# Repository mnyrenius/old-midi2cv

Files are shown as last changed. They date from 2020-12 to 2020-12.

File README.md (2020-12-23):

# old-midi2cv

PCB design + software for a midi2cv eurorack module.

I created it in 2016 and it has been installed in my rack since then.
It doesn't have any cool features and is probably really crappy, but it kind of works.

## Schematics




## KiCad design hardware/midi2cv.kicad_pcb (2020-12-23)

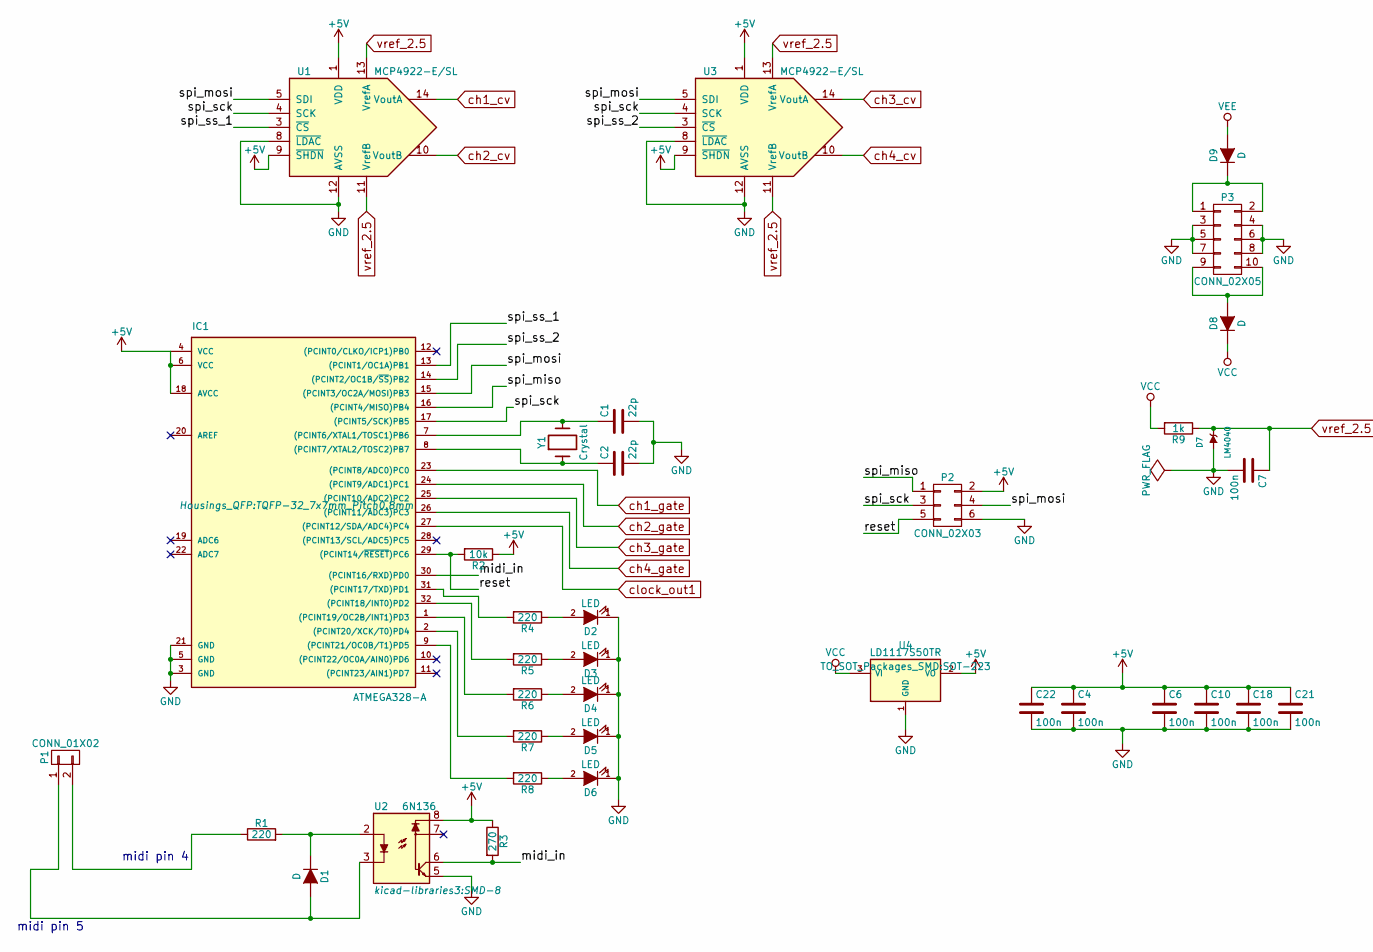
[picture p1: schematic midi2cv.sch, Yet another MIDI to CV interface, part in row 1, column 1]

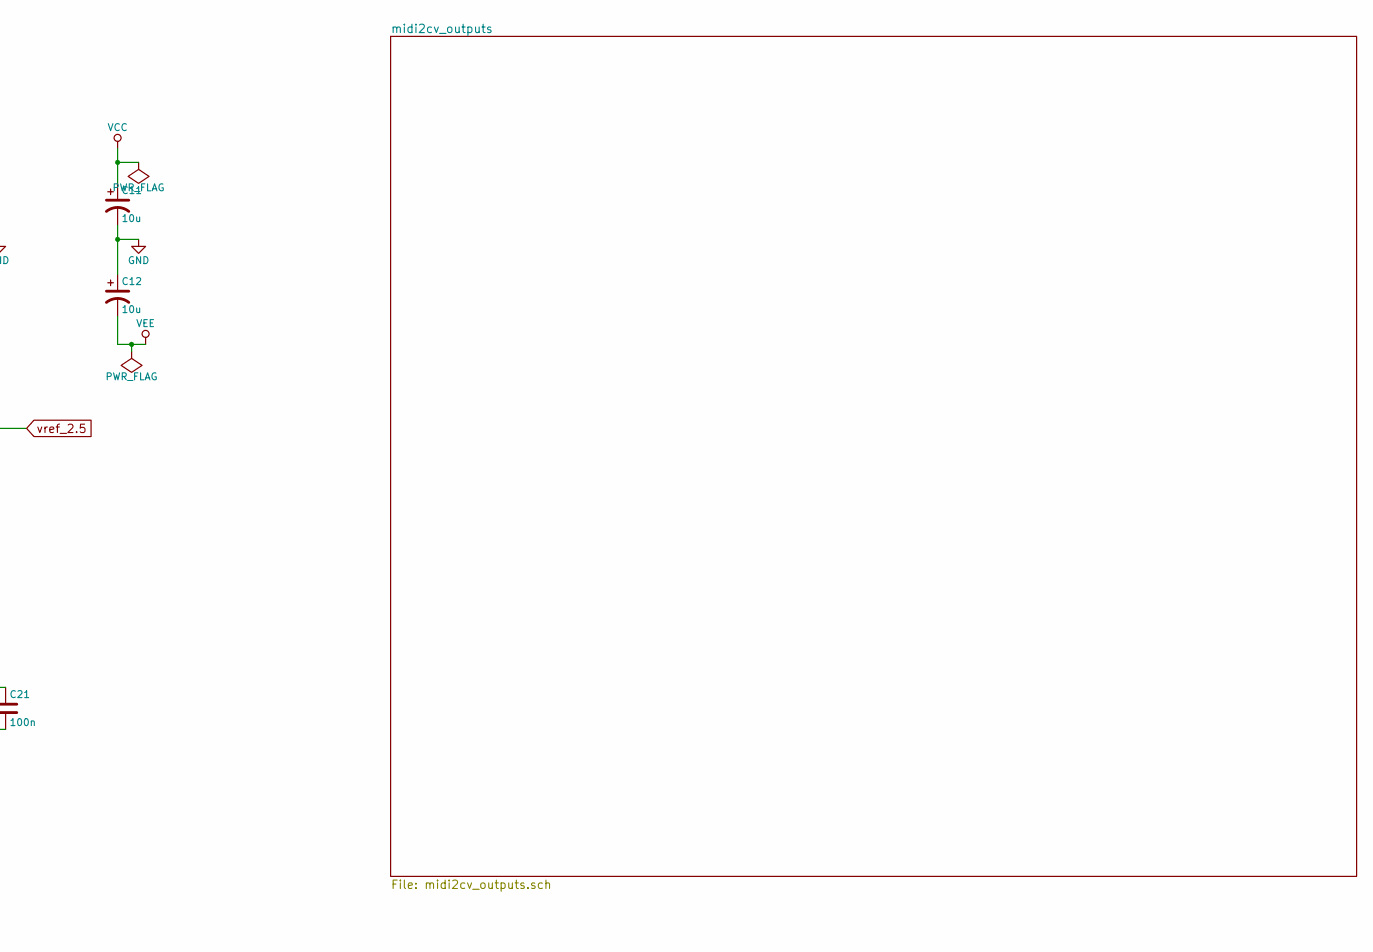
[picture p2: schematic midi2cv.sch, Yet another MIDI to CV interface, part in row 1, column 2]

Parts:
C1, C2: 22p; C_0603_HandSoldering
C4, C6, C7, C10, C18, C21, C22: 100n; C_0603_HandSoldering
C11, C12: 10u; c_elec_4x5.3
D1, D8, D9: D; SOD123
D2, D3, D4, D5, D6: LED; LED-3MM
D7: LM4040; SOT-23
IC1: ATMEGA328-A; TQFP-32_7x7mm_Pitch0.8mm
P1: CONN_01X02; Pin_Header_Straight_1x02
P2: CONN_02X03; Pin_Header_Straight_2x03
P3: CONN_02X05; Pin_Header_Straight_2x05
R1, R4, R5, R6, R7, R8: 220; R_0603_HandSoldering
R2: 10k; R_0603_HandSoldering
R3: 270; R_0603_HandSoldering
R9: 1k; R_0603_HandSoldering
U1, U3: MCP4922-E/SL; SOIC-14_N
U2: 6N136; SMD-8
U4: LD1117S50TR; SOT-223
Y1: Crystal; Crystal_HC49-SD_SMD

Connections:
+5V: C4.1, C6.1, C10.1, C18.1, C21.1, C22.1, IC1.4 (VCC), IC1.6 (VCC), IC1.18 (AVCC), P2.2, R2.1, R3.1, U1.1 (VDD), U1.9 (~SHDN~), U2.8, U3.1 (VDD), U3.9 (~SHDN~), U4.2 (VO)
/midi_in: IC1.30 ((PCINT16/RXD)PD0), R3.2, U2.6
/reset: IC1.29 ((PCINT14/~RESET~)PC6), P2.5, R2.2
/spi_miso: IC1.16 ((PCINT4/MISO)PB4), P2.1
/spi_mosi: IC1.15 ((PCINT3/OC2A/MOSI)PB3), P2.4, U1.5 (SDI), U3.5 (SDI)
/spi_sck: IC1.17 ((PCINT5/SCK)PB5), P2.3, U1.4 (SCK), U3.4 (SCK)
/spi_ss_1: IC1.13 ((PCINT1/OC1A)PB1), U1.3 (~CS~)
/spi_ss_2: IC1.14 ((PCINT2/OC1B/~SS~)PB2), U3.3 (~CS~)
GND: C1.2, C2.2, C4.2, C6.2, C7.2, C10.2, C11.2, C12.1, C18.2, C21.2, C22.2, D2.1 (K), D3.1 (K), D4.1 (K), D5.1 (K), D6.1 (K), D7.2 (A), IC1.3 (GND), IC1.5 (GND), IC1.21 (GND), P2.6, P3.3, P3.4, P3.5, P3.6, P3.7, P3.8, U1.8 (~LDAC~), U1.12 (AVSS), U2.5, U3.8 (~LDAC~), U3.12 (AVSS), U4.1 (GND); also elsewhere on the board
unnamed: C1.1, IC1.7 ((PCINT6/XTAL1/TOSC1)PB6), Y1.2
unnamed: C2.1, IC1.8 ((PCINT7/XTAL2/TOSC2)PB7), Y1.1
unnamed: D1.1 (K), R1.2, U2.2
unnamed: D1.2 (A), P1.1, U2.3
unnamed: D2.2 (A), R4.1
unnamed: D3.2 (A), R5.1
unnamed: D4.2 (A), R6.1
unnamed: D5.2 (A), R7.1
unnamed: D6.2 (A), R8.1
unnamed: D8.2 (A), P3.9, P3.10
unnamed: D9.1 (K), P3.1, P3.2
unnamed: IC1.1 ((PCINT19/OC2B/INT1)PD3), R6.2
unnamed: IC1.2 ((PCINT20/XCK/T0)PD4), R7.2
unnamed: IC1.9 ((PCINT21/OC0B/T1)PD5), R8.2
unnamed: IC1.31 ((PCINT17/TXD)PD1), R4.2
unnamed: IC1.32 ((PCINT18/INT0)PD2), R5.2
unnamed: P1.2, R1.1
VCC: C11.1, D8.1 (K), R9.2, U4.3 (VI); also elsewhere on the board
VEE: C12.2, D9.2 (A); also elsewhere on the board
ch1_cv: U1.14 (VoutA); also elsewhere on the board
ch1_gate: IC1.23 ((PCINT8/ADC0)PC0); also elsewhere on the board
ch2_cv: U1.10 (VoutB); also elsewhere on the board
ch2_gate: IC1.24 ((PCINT9/ADC1)PC1); also elsewhere on the board
ch3_cv: U3.14 (VoutA); also elsewhere on the board
ch3_gate: IC1.25 ((PCINT10/ADC2)PC2); also elsewhere on the board
ch4_cv: U3.10 (VoutB); also elsewhere on the board
ch4_gate: IC1.26 ((PCINT11/ADC3)PC3); also elsewhere on the board
clock_out1: IC1.27 ((PCINT12/SDA/ADC4)PC4); also elsewhere on the board
vref_2.5: C7.1, D7.1 (K), R9.1, U1.11 (VrefB), U1.13 (VrefA), U3.11 (VrefB), U3.13 (VrefA); also elsewhere on the board

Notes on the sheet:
midi pin 4
midi pin 5

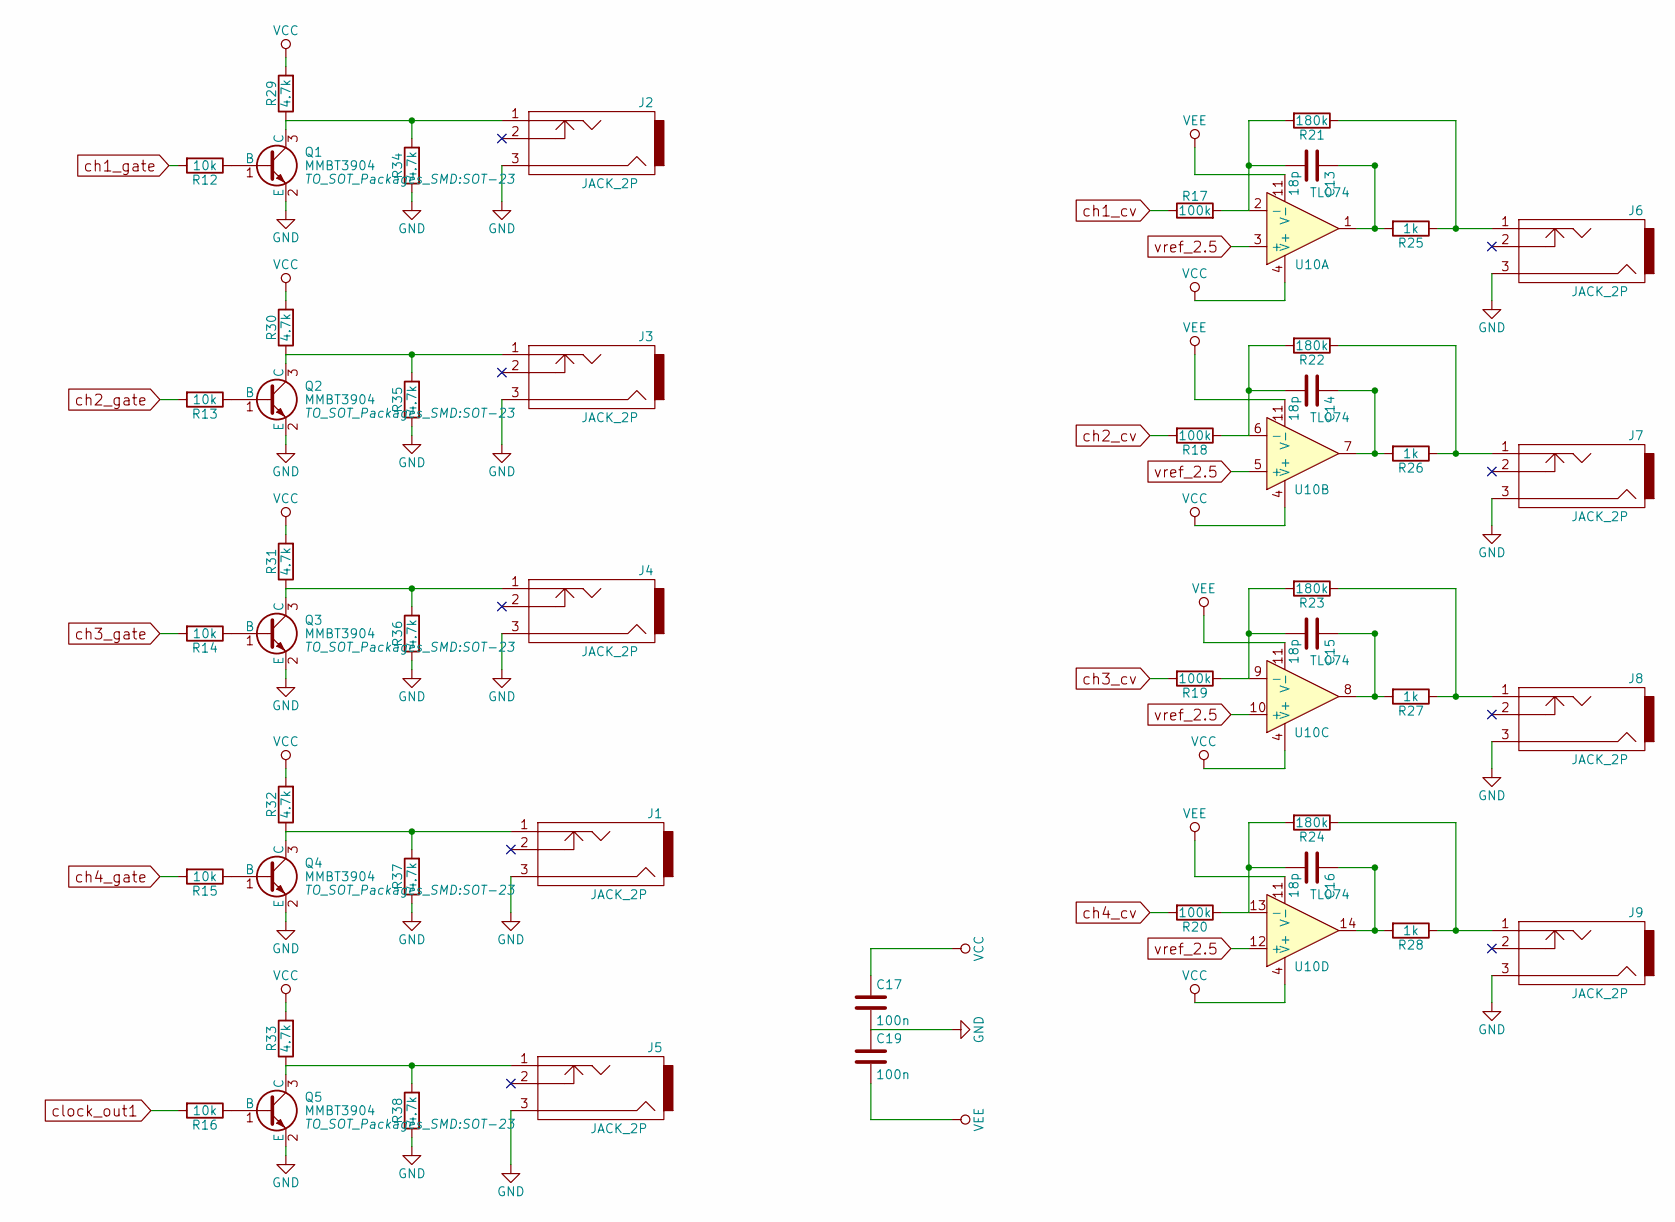
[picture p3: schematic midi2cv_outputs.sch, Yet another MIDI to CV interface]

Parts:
C13, C14, C15, C16: 18p; C_0603_HandSoldering
C17, C19: 100n; C_0603_HandSoldering
J1, J2, J3, J4, J5, J6, J7, J8, J9: JACK_2P; THONKICONN2
Q1, Q2, Q3, Q4, Q5: MMBT3904; SOT-23
R12, R13, R14, R15, R16: 10k; R_0603_HandSoldering
R17, R18, R19, R20: 100k; R_0603_HandSoldering
R21, R22, R23, R24: 180k; R_0603_HandSoldering
R25, R26, R27, R28: 1k; R_0603_HandSoldering
R29, R30, R31, R32, R33, R34, R35, R36, R37, R38: 4.7k; R_0603_HandSoldering
U10: TL074; SOIC-14_N

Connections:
GND: C17.2, C19.1, J1.3, J2.3, J3.3, J4.3, J5.3, J6.3, J7.3, J8.3, J9.3, Q1.2 (E), Q2.2 (E), Q3.2 (E), Q4.2 (E), Q5.2 (E), R34.1, R35.1, R36.1, R37.1, R38.1; also elsewhere on the board
unnamed: C13.1, R25.2, U10.1
unnamed: C13.2, R17.2, R21.2, U10.2 (-)
unnamed: C14.1, R26.2, U10.7
unnamed: C14.2, R18.1, R22.2, U10.6 (-)
unnamed: C15.1, R27.2, U10.8
unnamed: C15.2, R19.1, R23.2, U10.9 (-)
unnamed: C16.1, R28.2, U10.14
unnamed: C16.2, R20.1, R24.2, U10.13 (-)
unnamed: J1.1, Q4.3 (C), R32.1, R37.2
unnamed: J2.1, Q1.3 (C), R29.1, R34.2
unnamed: J3.1, Q2.3 (C), R30.1, R35.2
unnamed: J4.1, Q3.3 (C), R31.1, R36.2
unnamed: J5.1, Q5.3 (C), R33.1, R38.2
unnamed: J6.1, R21.1, R25.1
unnamed: J7.1, R22.1, R26.1
unnamed: J8.1, R23.1, R27.1
unnamed: J9.1, R24.1, R28.1
unnamed: Q1.1 (B), R12.1
unnamed: Q2.1 (B), R13.1
unnamed: Q3.1 (B), R14.1
unnamed: Q4.1 (B), R15.1
unnamed: Q5.1 (B), R16.1
VCC: C17.1, R29.2, R30.2, R31.2, R32.2, R33.2, U10.4 (V+); also elsewhere on the board
VEE: C19.2, U10.11 (V-); also elsewhere on the board
ch1_cv: R17.1; also elsewhere on the board
ch1_gate: R12.2; also elsewhere on the board
ch2_cv: R18.2; also elsewhere on the board
ch2_gate: R13.2; also elsewhere on the board
ch3_cv: R19.2; also elsewhere on the board
ch3_gate: R14.2; also elsewhere on the board
ch4_cv: R20.2; also elsewhere on the board
ch4_gate: R15.2; also elsewhere on the board
clock_out1: R16.2; also elsewhere on the board
vref_2.5: U10.3 (+), U10.5 (+), U10.10 (+), U10.12 (+); also elsewhere on the board

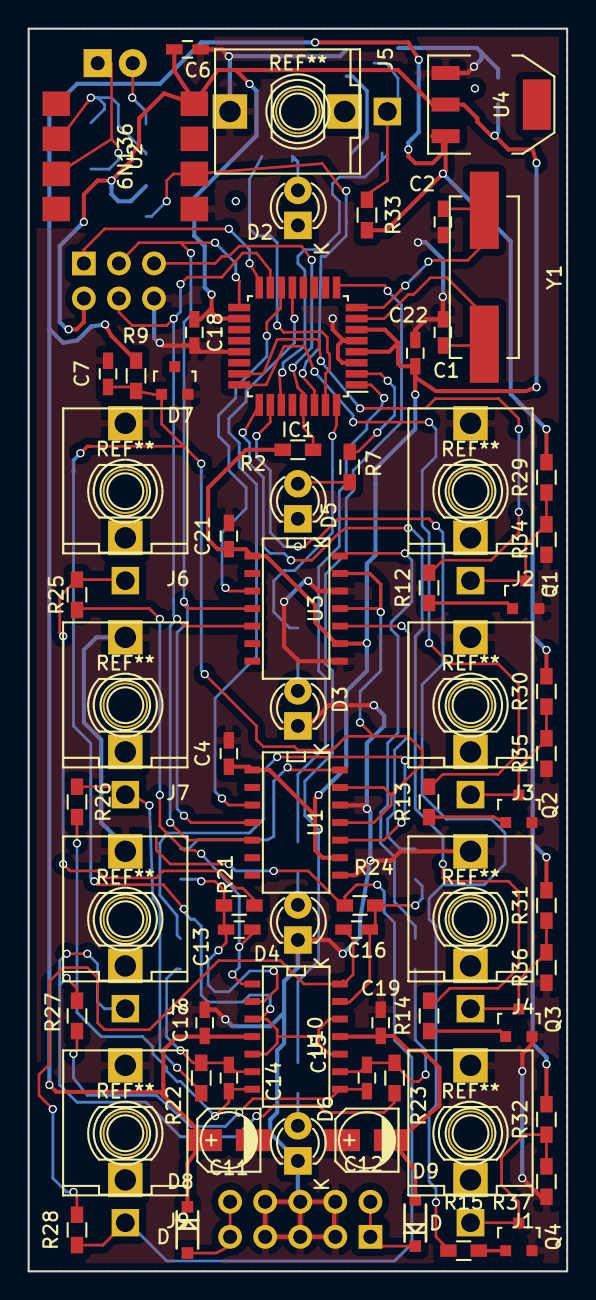
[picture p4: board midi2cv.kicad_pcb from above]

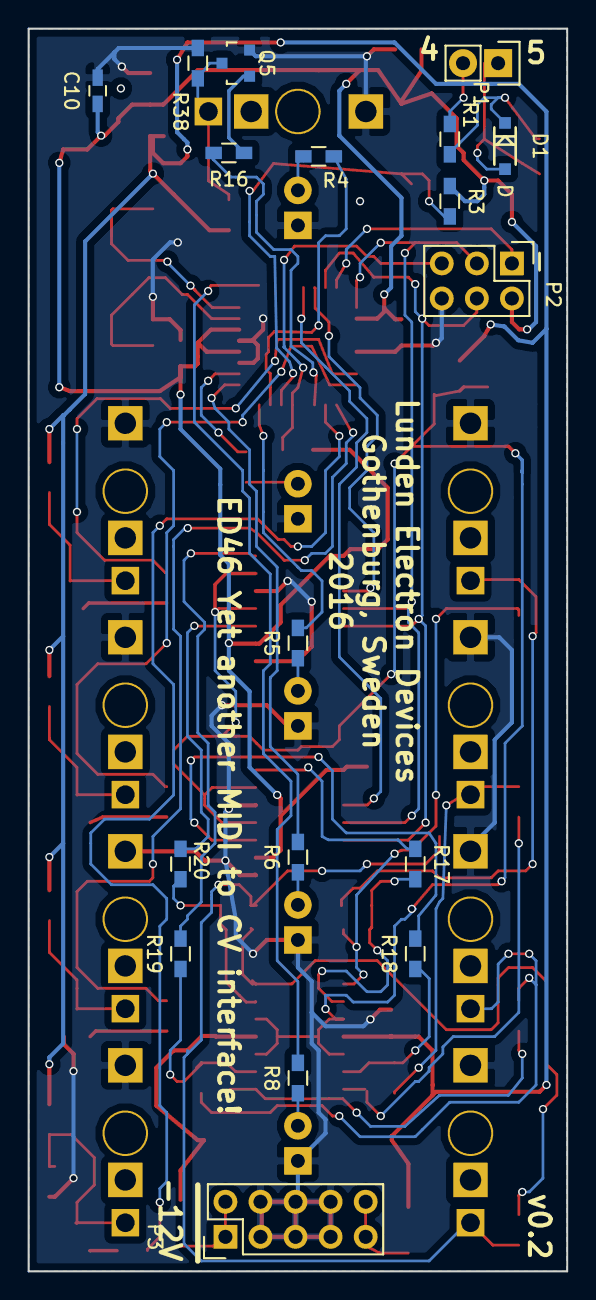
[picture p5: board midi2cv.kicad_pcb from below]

Board: 2 copper layers, 39.0 x 90.0 mm, 86 parts (18 on the bottom side), 60 nets.

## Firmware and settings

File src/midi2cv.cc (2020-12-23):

#include "dac.h"
#include "uart.h"
#include "midi.h"
#include "ringbuffer.h"

#include <avr/io.h>
#include <avr/interrupt.h>
#include <util/delay.h>
#include <stdlib.h>
   
/* ---------- PIN CONFIGURATION ----------
 *
 * PORTB
 *  1 - mcp4922 1 slave select
 *  2 - mcp4922 2 slave select
 *  5 - mcp4922 sck
 *  3 - mcp4922 mosi
 *  
 * PORTC
 *  0 - gate channel 1
 *  1 - gate channel 2 
 *  2 - gate channel 3 
 *  3 - gate channel 4 
 *  4 - clock 1 
 *
 * PORTD
 *  0 - midi in
 *  1 - led D2
 *  2 - led D3
 *  3 - led D4
 *  4 - led D5
 *  5 - led D6
 *
 * ------------------------------------ */


/* --------- CV OUTPUT STAGE NOTES ---------
 *
 * V_out = - V_dac (R1/R2) + V_ref ((R1+R2)/R1)
 *
 * R1 = 100k
 * R2 = 180k
 *
 * ------------------------------------ */

const uint8_t  NUM_CHANNELS         = 4;
const uint8_t  NUM_OCTAVES          = 10;
const uint8_t  NUM_STEPS_PER_OCTAVE = 12;
const uint16_t NUM_DAC_VALUES       = 4096;

struct channel_t
{
  int32_t  cv;
  bool     gate_on;
  int32_t  pitch_bend;
  int32_t  calibration_offsets[10];
};
 
namespace bit
{

inline void set (volatile uint8_t & port, uint8_t bit)
{
  port |= _BV (bit);
}

inline void clear (volatile uint8_t & port, uint8_t bit)
{
  port &= ~ _BV (bit);
}

}

uint16_t   _dac_values[120];

struct Gate
{
  struct port_config
  {
    volatile uint8_t & port;
    uint8_t            pin[4];
  };

  struct config
  {
    port_config gate_config;
    port_config led_config;
  };

  Gate (const config & c)
    : _config (c)
  {
  }

  void on (uint16_t channel)
  {
    auto gconf = _config.gate_config;
    bit::clear (gconf.port, gconf.pin[channel]);
 
    auto lconf = _config.led_config;
    bit::set (lconf.port, lconf.pin[channel]); 
  }

  void off (uint16_t channel)
  {
    auto gconf = _config.gate_config;
    bit::set (gconf.port, gconf.pin[channel]);
 
    auto lconf = _config.led_config;
    bit::clear (lconf.port, lconf.pin[channel]);  
  }

  config _config;
};

void generate_dac_values (uint16_t * values)
{
  for (uint16_t i = 0; i < 120; ++i)
  {
    values[i] = 4096 - 38 * i;
  }
}
  
uint16_t midi_note_to_cv (
        uint16_t * values,
        uint8_t note)
    {
      if (note >= 0 && note < 120)
      {
        return values[note];
      }

      else
      {
        return 1024;
      }
    } 

void output_channels (
    channel_t * channels,
    Dac & dac,
    Gate & gate)
{
  for (uint16_t i = 0; i < NUM_CHANNELS; ++i)
  {
    auto & channel = channels[i];
    dac.write (i, channel.cv + channel.pitch_bend);
    if (channel.gate_on)
    {
      gate.on (i);
    }

    else
    {
      gate.off (i);
    }
  }
}
  
struct MidiHandler
{
  using data = channel_t;

  static void note_on (channel_t * channels, uint8_t channel, uint8_t note)
  {
    auto & ch = channels[channel];

    ch.cv = 
      midi_note_to_cv (_dac_values, note) +
      ch.calibration_offsets[note/12];

    ch.gate_on = true;
  }

  static void note_off (channel_t * channels, uint8_t channel)
  {
    channels[channel].gate_on = false;
  }

  static void pitch_bend (channel_t * channels, uint8_t channel, int32_t value)
  {
    constexpr auto scale = 0x4000 / 24 / 38;
    int32_t bend = (8192 - value) / scale;
    channels[channel].pitch_bend = bend;
  }
  
  static void clock (uint8_t counter)
  {
    switch (counter)
    {
      case 0:
      case 12:
        PORTC &= ~ _BV (PC4);
        PORTD |= _BV (PD1);
        break;

      case 6:
      case 18:
      case 255: // Stop
        PORTC |= _BV (PC4);
        PORTD &= ~ _BV (PD1);
        break;

      default:
        break;
    }
  }
};    

int main ()
{
  // Setup gate and clock outputs
  DDRC  |= _BV (PC0) | _BV (PC1) | _BV (PC2) | _BV (PC3) | _BV (PC4);
  PORTC |= _BV (PC0) | _BV (PC1) | _BV (PC2) | _BV (PC3) | _BV (PC4); 

  // Setup leds
  DDRD |= _BV (PD1) | _BV (PD2) | _BV (PD3) | _BV (PD4) | _BV (PD5);
  PORTD &= ~ 0x3e;
  
  Dac dac;
  Gate::config c
  {
    {
      PORTC,
      {
        PC0,
        PC1,
        PC2,
        PC3,
      }
    },
    {
      PORTD,
      {
        PD4,
        PD2,
        PD3,
        PD5,
      }
    },
  };

  Gate gate (c);

  generate_dac_values (_dac_values);
  channel_t channels[NUM_CHANNELS];
  
  for (int i = 0; i < NUM_CHANNELS; ++i)
  {
    channels[i].cv = 0;
    channels[i].gate_on = false;
    channels[i].pitch_bend = 0;

    for (int j = 0; j < 10; ++j)
    {
      channels[i].calibration_offsets[j] = 0;
    }
  }

  Uart serial;

  Midi<MidiHandler> midi (channels, serial);

  sei ();

  while (true)
  {
    midi.process_next ();
    output_channels (channels, dac, gate);
  }
}

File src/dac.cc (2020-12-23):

#include "dac.h"
#include "avr_types.h"

#include <avr/io.h>

Dac::Dac ()
{
  // Setup slave selects, sck and mosi
  DDRB |= _BV (PB1) | _BV (PB2) | _BV (PB3) | _BV (PB5);
 
  // Enable spi, master mode, fcpu / 64
  SPSR = 0;
  SPCR = _BV (SPE) | _BV (MSTR) | _BV (SPR1); 

  _config[0].slave_select = PB1;
  _config[0].dac_command  = 0x10;

  _config[1].slave_select = PB1;
  _config[1].dac_command  = 0x90;

  _config[2].slave_select = PB2;
  _config[2].dac_command  = 0x10;

  _config[3].slave_select = PB2;
  _config[3].dac_command  = 0x90;
}

Dac::~Dac ()
{
}

void Dac::write (uint8_t channel, uint16_t value)
{
  auto config = _config[channel];

  PORTB &= ~ _BV (config.slave_select);

  SPDR = (config.dac_command & 0xf0) | (0x0f & (value >> 8));
  while (!(SPSR & (1 << SPIF)));

  SPDR = value & 0x00ff;
  while (!(SPSR & (1 << SPIF)));

  PORTB |= _BV (config.slave_select);
}

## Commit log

2020-12-23 Copied files from old backup
    [midi2cv.kicad_pcb, midi2cv.sch, midi2cv_outputs.sch]
2020-12-23 Add schematics svg
